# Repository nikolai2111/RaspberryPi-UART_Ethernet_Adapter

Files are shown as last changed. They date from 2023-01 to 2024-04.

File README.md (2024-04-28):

<!-- Improved compatibility of back to top link: See: https://github.com/othneildrew/Best-README-Template/pull/73 -->

<!--
*** Thanks for checking out the Best-README-Template. If you have a suggestion
*** that would make this better, please fork the repo and create a pull request
*** or simply open an issue with the tag "enhancement".
*** Don't forget to give the project a star!
*** Thanks again! Now go create something AMAZING! :D
-->

<!-- PROJECT SHIELDS -->
<!--
*** I'm using markdown "reference style" links for readability.
*** Reference links are enclosed in brackets [ ] instead of parentheses ( ).
*** See the bottom of this document for the declaration of the reference variables
*** for contributors-url, forks-url, etc. This is an optional, concise syntax you may use.
*** https://www.markdownguide.org/basic-syntax/#reference-style-links
-->
[][contributors-url]
[][forks-url]
[][stars-url]
[][issues-url]
[][license-url]

<!-- PROJECT LOGO -->
<br />
<div align="center">

<h3 align="center">Raspberry Pi UART to Ethernet Adapter</h3>

  <p align="center">
    This adapter board enables the creation of a stand-alone, network-compatible device using any Raspberry Pi compatible UART daughterboard.
    <br />
    <a href="https://github.com/nikolai2111/RaspberryPi-UART_Ethernet_Adapter"><strong>Explore the docs »</strong></a>
    <br />
    <br />
    <a href="https://github.com/nikolai2111/RaspberryPi-UART_Ethernet_Adapter">View Demo</a>
    ·
    <a href="https://github.com/nikolai2111/RaspberryPi-UART_Ethernet_Adapter/issues/new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">Report Bug</a>
    ·
    <a href="https://github.com/nikolai2111/RaspberryPi-UART_Ethernet_Adapter/issues/new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">Request Feature</a>
  </p>
</div>

<!-- TABLE OF CONTENTS -->
<details>
  <summary>Table of Contents</summary>
  <ol>
    <li>
      <a href="#about-the-project">About The Project</a>
      <ul>
        <li><a href="#built-with">Built With</a></li>
      </ul>
    </li>
    <li>
      <a href="#getting-started">Getting Started</a>
      <ul>
        <li><a href="#prerequisites">Prerequisites</a></li>
        <li><a href="#Configure WIZ750SR">Configure WIZ750SR</a></li>
        <li><a href="#Confgure Z-Wave JS UI">Confgure Z-Wave JS UI</a></li>
      </ul>
    </li>
    <li><a href="#usage">Usage</a></li>
    <li><a href="#roadmap">Roadmap</a></li>
    <li><a href="#contributing">Contributing</a></li>
    <li><a href="#license">License</a></li>
    <li><a href="#contact">Contact</a></li>
    <li><a href="#acknowledgments">Acknowledgments</a></li>
  </ol>
</details>

<!-- ABOUT THE PROJECT -->
## About The Project

This adapter board enables the creation of a stand-alone, network-compatible device using any Raspberry Pi compatible UART daughterboard. The adapter board is used to connect the daughterboard of the Raspberry Pi and [WIZ750SR](https://docs.wiznet.io/Product/S2E-Module/WIZ750SR)-TTL. The adapter board connects the daughterboard of the Raspberry Pi to the [WIZ750SR](https://docs.wiznet.io/Product/S2E-Module/WIZ750SR)-TTL. It also provides a 5V and 3.3V power supply where necessary.

The adapter board was initially designed to connect the [RaZberry 7 Pro](https://z-wave.me/products/razberry/#slide-1) to [Home Assistant](https://www.home-assistant.io/) via TCP, without using a Raspberry Pi as a server. It can also be used with any Raspberry Pi daughterboard that only needs the TTL-UART interface. However, the following README refers to the use of the [RaZberry 7 Pro](https://z-wave.me/products/razberry/#slide-1) with [Home Assistant](https://www.home-assistant.io/). It is possible to map three GPIOs to the header, although this has not been tested yet.

The board or as a kit (incl. [WIZ750SR](https://www.digikey.de/de/products/detail/wiznet/WIZ750SR-TTL/8789618)) can be purchased [here](https://www.tindie.com/products/nikolai2111/raspberry-pi-uart-to-ethernet-adapter/). The board is available with three power supply options (power supply not inlcuded):
* [Barrel Jack 2.1x5.5 mm](https://www.digikey.com/en/products/detail/cui-devices/PJ-037A/1644545)
* [USB Micro](https://www.digikey.de/de/products/detail/amphenol-cs-fci/10118194-0001LF/2785389)
* [USB C](https://www.digikey.ch/de/products/detail/gct/USB4125-GF-A/13547388)

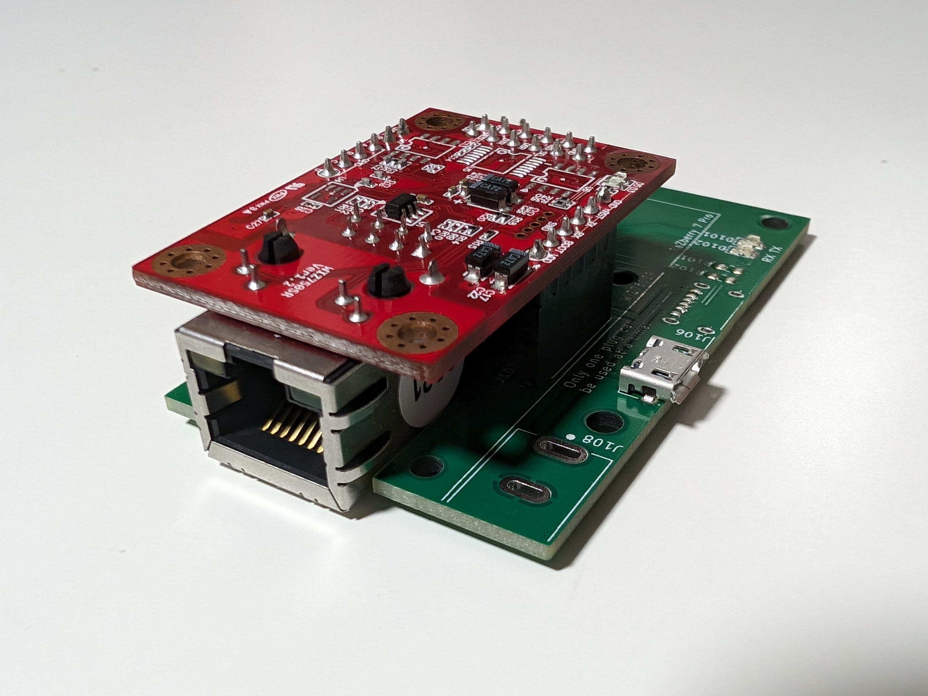
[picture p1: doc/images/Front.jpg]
Front


<p align="right">(<a href="#readme-top">back to top</a>)</p>

### Built With

* [][Kicad-url]

<p align="right">(<a href="#readme-top">back to top</a>)</p>

<!-- GETTING STARTED -->
## Getting Started

### Prerequisites
* [Home Assistant](https://www.home-assistant.io/) is running
* [Z-Wave JS UI](https://www.home-assistant.io/integrations/zwave_js/) installed
* [WIZnet-S2E-Tool-GUI](https://github.com/Wiznet/WIZnet-S2E-Tool-GUI) downloaded

### Configure WIZ750SR
1. Open the [WIZnet-S2E-Tool-GUI](https://github.com/Wiznet/WIZnet-S2E-Tool-GUI)
2. Click `Device Search`
3. Select device with double click
4. Set the `Basic Settings` as shown in the picture below
   
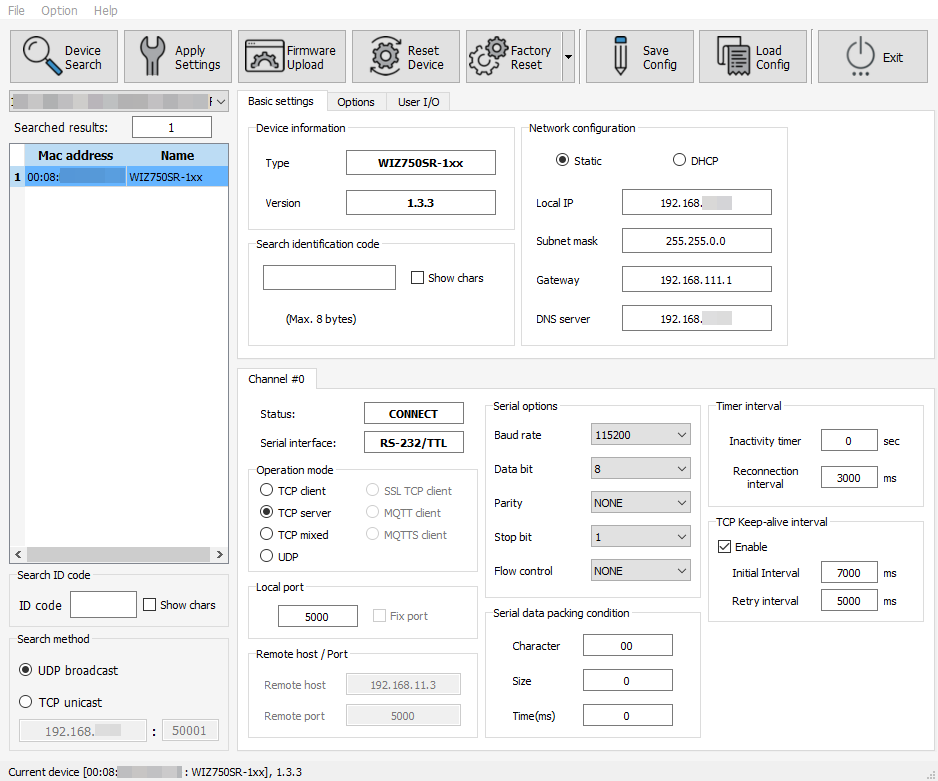
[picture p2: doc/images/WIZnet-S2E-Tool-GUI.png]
Basic Settings


### Confgure Z-Wave JS UI
1. Open [Home Assistant](homeassistant.local)
2. Open `Add-ons`
3. Click on `Z-Wave JS UI`
4. Start the add-on, if it's not running yet
5. Click on `OPEN WEB UI`
6. Go to `Settings`
7. Go to `Z-Wave`
8. And enter the IP and port below the `Serial Port` as shown in the picture blow. Use the scheme `tcp://your-ip:port`

Serial Port

<!-- USAGE EXAMPLES -->
## Usage

Use this space to show useful examples of how a project can be used. Additional screenshots, code examples and demos work well in this space. You may also link to more resources.

_For more examples, please refer to the [Documentation](https://example.com)_

<p align="right">(<a href="#readme-top">back to top</a>)</p>

<!-- ROADMAP -->
## Roadmap

* [ ] Test more than one device
* [ ] Offer [WIZ750SR](https://docs.wiznet.io/Product/S2E-Module/WIZ750SR) in the shop
* [ ] Offer PoE adapter in the shop

See the [open issues](https://github.com/nikolai2111/RaspberryPi-UART_Ethernet_Adapter/issues) for a full list of proposed features (and known issues).

<p align="right">(<a href="#readme-top">back to top</a>)</p>

<!-- CONTRIBUTING -->
## Contributing

Contributions are what make the open source community such an amazing place to learn, inspire, and create. Any contributions you make are **greatly appreciated**.

If you have a suggestion that would make this better, please fork the repo and create a pull request. You can also simply open an issue with the tag "enhancement".
Don't forget to give the project a star! Thanks again!

1. Fork the Project
2. Create your Feature Branch (`git checkout -b feature/AmazingFeature`)
3. Commit your Changes (`git commit -m 'Add some AmazingFeature'`)
4. Push to the Branch (`git push origin feature/AmazingFeature`)
5. Open a Pull Request

<p align="right">(<a href="#readme-top">back to top</a>)</p>

<!-- LICENSE -->
## License

Distributed under the [CERN-OHL-P](LICENSE) License. See `LICENSE` for more information. The license for all other sources remains the same and is still valid.

<p align="right">(<a href="#readme-top">back to top</a>)</p>

<!-- CONTACT -->
## Contact

Nikolai Zoller - [nikolai.zoller@hotmail.com](mailto:nikolai.zoller@hotmail.com)

Project Link: [https://github.com/nikolai2111/RaspberryPi-UART_Ethernet_Adapter](https://github.com/nikolai2111/RaspberryPi-UART_Ethernet_Adapter)

<p align="right">(<a href="#readme-top">back to top</a>)</p>

<!-- ACKNOWLEDGMENTS -->
## Acknowledgments

The main concept was initially proposed by an anonymous colleague. The development, production, and sale are carried out with their consent.

<p align="right">(<a href="#readme-top">back to top</a>)</p>

Source: [Best-README-Template](https://github.com/othneildrew/Best-README-Template)

<!-- MARKDOWN LINKS & IMAGES -->
<!-- https://www.markdownguide.org/basic-syntax/#reference-style-links -->
[contributors-shield]: https://img.shields.io/github/contributors/nikolai2111/RaspberryPi-UART_Ethernet_Adapter.svg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
[contributors-url]: https://github.com/nikolai2111/RaspberryPi-UART_Ethernet_Adapter/graphs/contributors
[forks-shield]: https://img.shields.io/github/forks/nikolai2111/RaspberryPi-UART_Ethernet_Adapter.svg?style=for-the-badge
[forks-url]: https://github.com/nikolai2111/RaspberryPi-UART_Ethernet_Adapter/network/members
[stars-shield]: https://img.shields.io/github/stars/nikolai2111/RaspberryPi-UART_Ethernet_Adapter.svg?style=for-the-badge
[stars-url]: https://github.com/nikolai2111/RaspberryPi-UART_Ethernet_Adapter/stargazers
[issues-shield]: https://img.shields.io/github/issues/nikolai2111/RaspberryPi-UART_Ethernet_Adapter.svg?style=for-the-badge
[issues-url]: https://github.com/nikolai2111/RaspberryPi-UART_Ethernet_Adapter/issues
[license-shield]: https://img.shields.io/github/license/nikolai2111/RaspberryPi-UART_Ethernet_Adapter.svg?style=for-the-badge
[license-url]: https://github.com/nikolai2111/RaspberryPi-UART_Ethernet_Adapter/blob/master/LICENSE.txt
[Kicad-logo]: https://upload.wikimedia.org/wikipedia/commons/5/59/KiCad-Logo.svg
[Kicad-url]: https://www.kicad.org/

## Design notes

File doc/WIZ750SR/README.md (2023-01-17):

# WIZ750SR

## Data sheet
### WIZ750SR Connector Specification
#### 6x2 Data Pin Connector
6x2 Data Pin Connector

#### 1x6 ISP Connector
1x6 ISP Connector

#### 1x6 Expansion GPIO & APP BOOT
1x6 Expansion GPIO & APP BOOT

### WIZ750SR Dimension
 -  45mm x 30mm (PCB board size)
 -  48mm x 30mm x 18mm (Included part size)

Rev1.2

## Links
 - [Overview WIZ750SR](https://www.wiznet.io/product-item/wiz750sr/)
 - [Data sheet WIZ750SR](https://docs.wiznet.io/Product/S2E-Module/WIZ750SR/datasheet)
 - [User's Manual-[EN]](https://docs.wiznet.io/Product/S2E-Module/WIZ750SR/users-manual-EN)
 - [Command Manual-[EN]](https://docs.wiznet.io/Product/S2E-Module/WIZ750SR/command-manual-EN)
 - [Trouble Shooting-[EN]](https://docs.wiznet.io/Product/S2E-Module/WIZ750SR/trouble-shooting-EN)
 - [WIZ750SR Series Downloads](https://docs.wiznet.io/Product/S2E-Module/WIZ750SR/download)
 - [Technical References](https://docs.wiznet.io/Product/S2E-Module/WIZ750SR/technical-references)

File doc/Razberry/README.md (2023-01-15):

# Razberry 2.1

## Data sheet

## Raspberry Pinout
Raspberry Pinout

## Links
 none

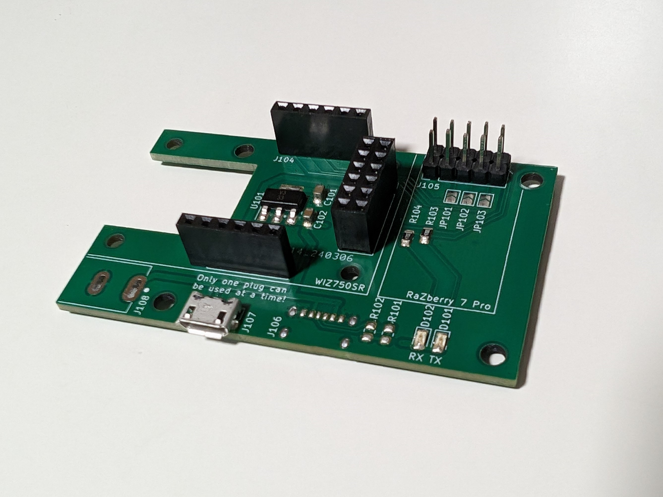
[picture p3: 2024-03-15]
doc/images/PCB-only.jpg

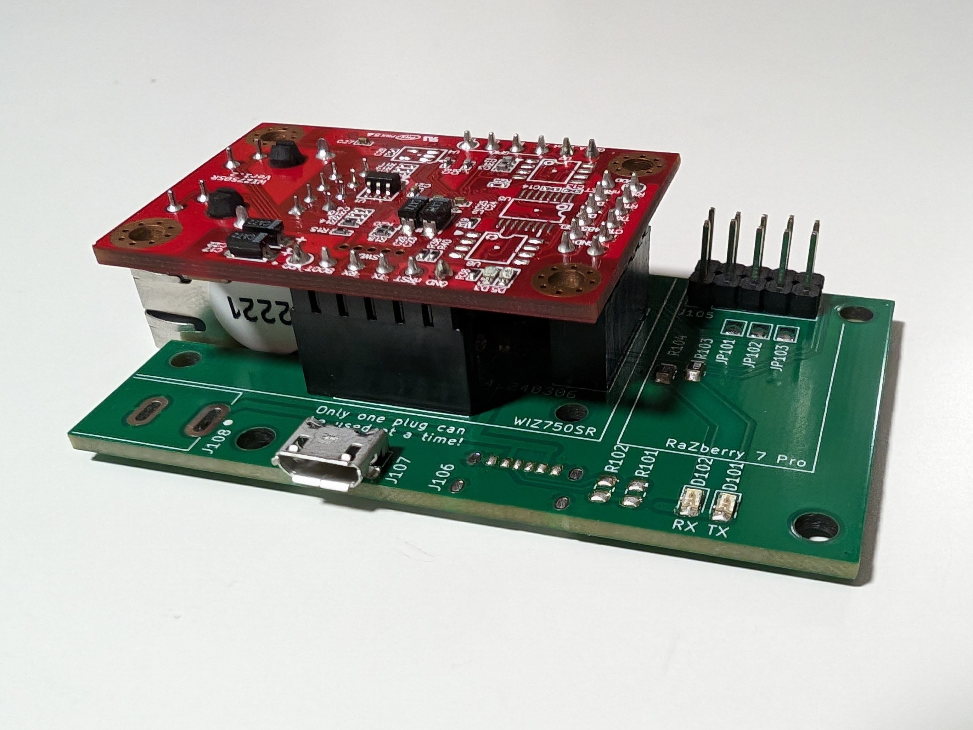
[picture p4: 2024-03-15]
doc/images/Side.jpg

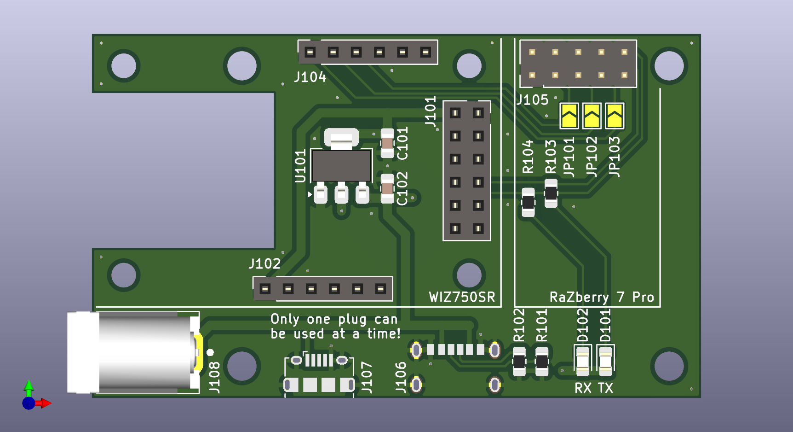
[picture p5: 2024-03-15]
PCB-3D_Top_B.png

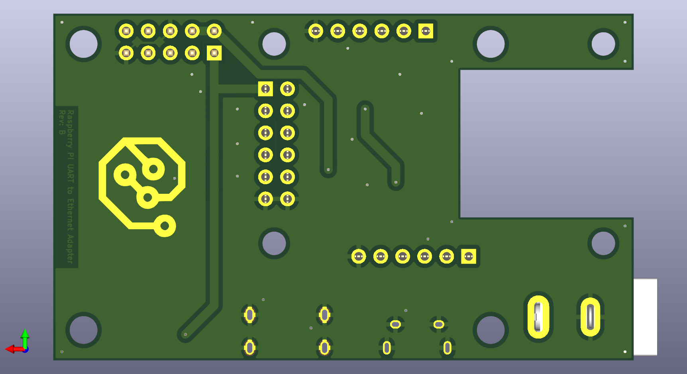
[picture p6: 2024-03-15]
PCB-3D_Bot_B.png

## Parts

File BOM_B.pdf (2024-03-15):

Reference | Value | Footprint | Qty | DNP | Manufacturer Part No. | Vendor | Vendor Part No.
C101 | 100µF | Capacitor_SMD:C_0805_2012Metric_Pad1.18x1.45mm_HandSolder | 1 | CL21A107MQYNNWE | Digikey | 1276-CL21A107MQYNNWECT-ND
C102 | 10µF | Capacitor_SMD:C_0805_2012Metric_Pad1.18x1.45mm_HandSolder | 1 | CL21A106KOQNNNE | Digikey | 1276-1096-1-ND
D101,D102 | GN | LED_SMD:LED_0805_2012Metric_Pad1.15x1.40mm_HandSolder | 2 | LTST-C171GKT | Digikey | 160-1423-1-ND
J101 | Conn_02x06_Odd_Even | Connector_PinSocket_2.54mm:PinSocket_2x06_P2.54mm_Vertical | 1 | RS2-12-G | Digikey | 2057-RS2-12-G-ND
J102,J104 | Conn_01x06 | Connector_PinSocket_2.54mm:PinSocket_1x06_P2.54mm_Vertical | 2 | RS1-06-G | Digikey | 2057-RS1-06-G-ND
J105 | Conn_02x05_Odd_Even | Connector_PinHeader_2.54mm:PinHeader_2x05_P2.54mm_Vertical | 1 | PH2-10-UA | Digikey | 2057-PH2-10-UA-ND
J106 | USB4125-GF-A | Connectors_User:GCT_USB4125-GF-A | 1 | USB4125-GF-A | Digikey | 2073-USB4125-GF-ACT-ND
J107 | USB_B_Micro | Connector_USB:USB_Micro-B_Amphenol_10118194_Horizontal | 1 | 10118194-0001LF | Digikey | 609-4618-1-ND
J108 | Barrel_Jack | Connector_User:CUI_PJ-037A_Board-Edge | 1 | PJ-037A | Digikey | CP-037A-ND
R101,R102 | 5.1k | Resistor_SMD:R_0805_2012Metric_Pad1.20x1.40mm_HandSolder | 2 | RC0805FR-075K1L | Digikey | 311-5.10KCRCT-ND
R103,R104 | 470R | Resistor_SMD:R_0805_2012Metric_Pad1.20x1.40mm_HandSolder | 2 | RC0805FR-07470RL | Digikey | 311-470CRCT-ND
U101 | TLV1117-33 | Package_TO_SOT_SMD:SOT-223-3_TabPin2 | 1 | TLV1117-33CDCYR | Digikey | 296-21112-1-ND

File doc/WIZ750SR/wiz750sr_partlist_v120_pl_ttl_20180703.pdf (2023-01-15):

Item | Q.ty | Reference | Part | Tech. Characteristics | Package
1 | 9 | C1,C6,C18,C19,C20,C21,C24,C25,C27 | 0.1uF | 50V-5% Ceramic | CASE 0402
2 | 4 | C17,C22,C23,C26 | 10uF/16V | Tantal CAP, A Size, 10uF/16V, +/-20% | EIA/IECQ 3216
3 | 2 | C2,C3 | 30pF | 25V-20% Ceramic | CASE 0402
4 | 2 | C8,C9 | 27pF | 50V-5% Ceramic | CASE 0402
5 | 1 | C7 | 1nF/2kV | 1nF/2kV Ceramic | CASE 1808(4520)
6 | 1 | D1 | Red LED | CHIP-LED, Red | CASE 0603
7 | 2 | D2,D3 | Blue LED | CHIP-LED, Blue | CASE 0603
8 | 2 | D4,D5 | Green LED | CHIP-LED, Green | CASE 0603
9 | 1 | J1 | 2.54mm Pin haeder 6x2 | 2.54mm Pin haeder 6x2, Male | DIP
10 | 2 | J2,J4 | 2.54mm Pin haeder 1x6 | 2.54mm Pin haeder 1x6, Male | DIP
11 | 2 | L1,L2 | HH-1M1608-121JT | Bead for Power Line, 120[ohm] | CASE 0603
12 | 1 | P1 | BS-RB10005 | Transformer + RJ45 + LED, Industrial, UDE | DIP
13 | 3 | R18,R19,R20 | 5.1K | 1/10W-5% SMD | CASE 0402
14 | 1 | R16 | 6.19K 1% | 1/10W-1% SMD | CASE 0402
15 | 1 | R1 | 1M | 1/10W-5% SMD | CASE 0402
16 | 5 | R14,R15,R36,R39,R40 | 330R | 1/10W-5% SMD | CASE 0402
17 | 2 | R37,R38 | 1K | 1/10W-5% SMD | CASE 0402
18 | 6 | R2,R6,R13,R17,R33,R42 | 4.7K | 1/10W-5% SMD | CASE 0402
19 | 4 | R21,R22,R23,R24 | 0R | 1/10W-5% SMD | CASE 0402
20 | 4 | R4,R5,R7,R8 | 3.3R | 1/10W-5% SMD | CASE 0402
21 | 1 | U1 | TPD4S009DBVR | 4-Channel ESD Protection IC | SOT-23(DBV)
22 | 1 | U2 | W7500P | WIZnet ARM Cortex-M0, Add PHY | LQFP64
23 | 1 | U3 | MIC811SUY | Microprocessor Reset Circuits | SOT-143
24 | 1 | Y1 | 12MHz (TZ1067B-12MHz)X-tal 12MHz,3.2x2.5 SMD, CL=20pF | | SMD3225, 4-PAD
25 | 1 | Y2 | 82J0626-25.000MHz | X-tal 25MHz,3.2x2.5 SMD, CL=18pF,Industrial,ITTI | SMD3225, 4-PAD
26 | 1 | J3 | 1.27mm Pin haeder 1x5 | Not Mount | DIP
27 | 4 | R9,R10,R11,R12 | 49R9 1% | 1/10W-1% SMD (Not Mount) | CASE 0402
28 | 4 | R26,R27,R28,R29 | 200R | Not Mount
29 | 2 | R30,R31 | 120R | Not Mount
30 | 1 | U4 | 24AA16T-I/OT | EEPROM 2Kbyte (Not Mount) | SOT-23
31 | 1 | U5 | SP3232EBEY | Not Mount
32 | 2 | U6,U7 | SP3485EN-L | Not Mount
33 | 10 | C4,C5,C10,C11,C12,C13,C14,C15,C16,C28 | 0.1uF | Not Mount
34 | 5 | R3,R25,R34,R35,R41 | 4.7K | Not Mount
35 | 1 | | PCB | 4-Layer 45mm x 30mm

# WIZ750SR V1.2.0_TTL_Version Partlist

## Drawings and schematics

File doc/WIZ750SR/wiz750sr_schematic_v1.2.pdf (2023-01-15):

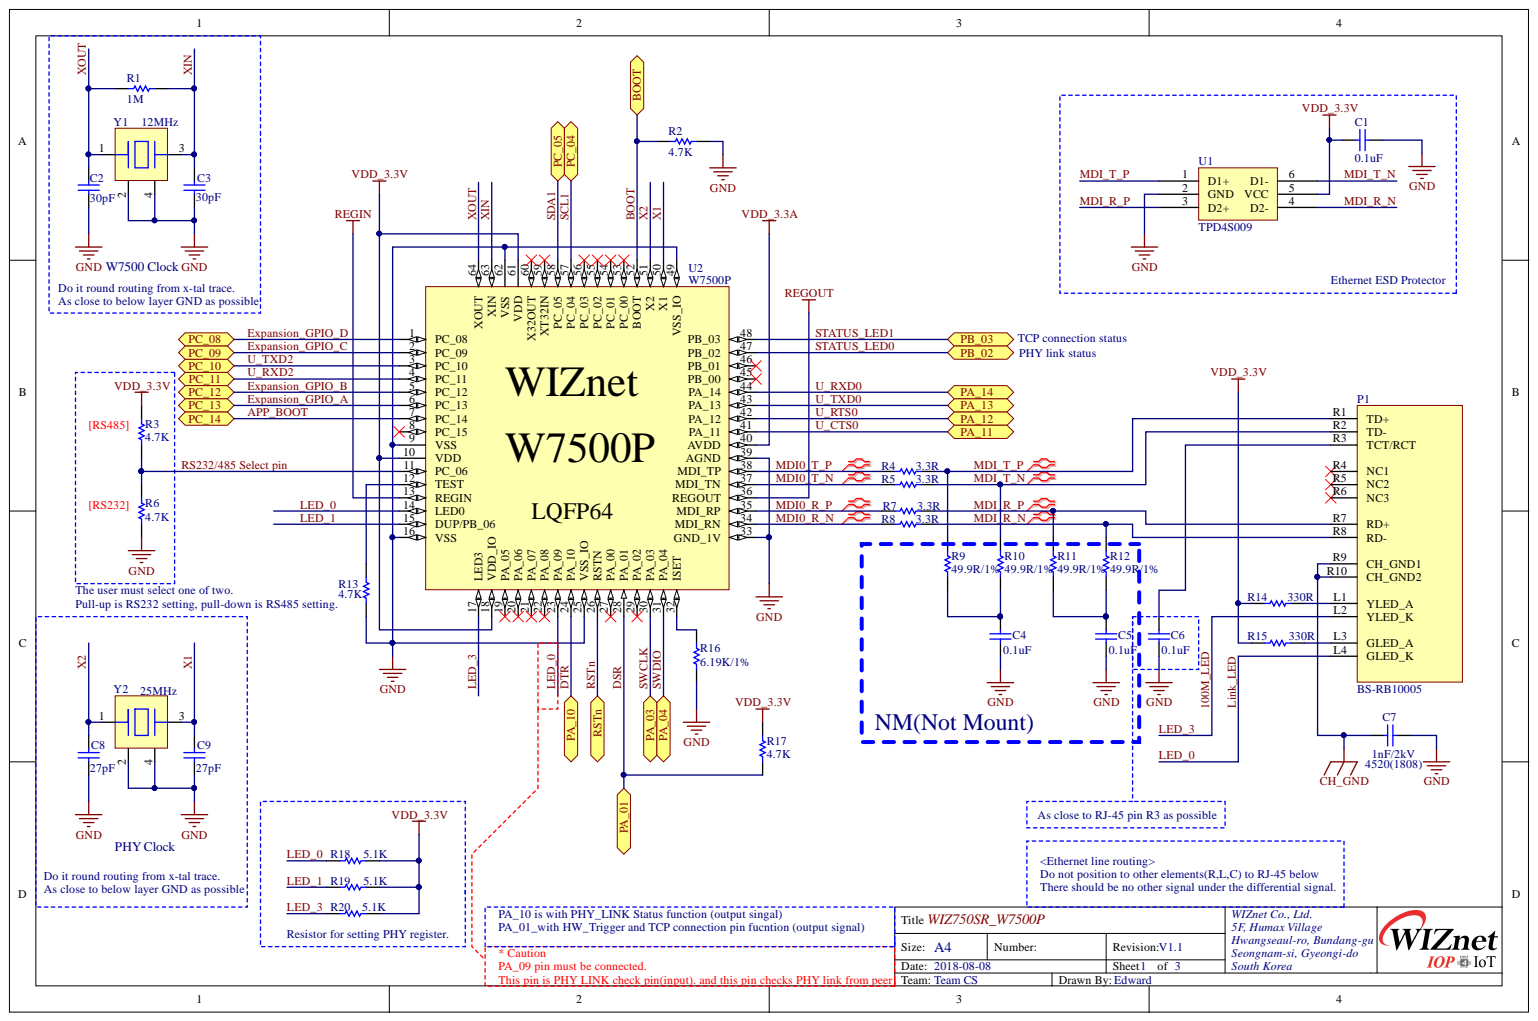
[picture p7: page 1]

48 SS_IO 49 X1 50 X2 51 BOOT 52 PC_00 53 PC_01 54 PC_02 55 PC_03 56 PC_04 57 PC_05 58 XT32IN 59 X32OUT 60 VDD 61 VSS 62 XIN 63 XOUT 64

Do it round routing from x-tal trace.
As close to below layer GND as possible

ISET 32 GND_1V 33 MDI_RN 34 MDI_RP 35 REGOUT 36 MDI_TN 37 MDI_TP 38 AGND 39 AVDD 40 PA_11 41 PA_12 42 PA_13 43 PA_14 44 PB_00 45 PB_01 46 PB_02 47 PB_03 V

U_TXD0
U_RTS0
U_CTS0 | TD- R2

VSS 9 | | | | TCT/RCT R3

REGIN 13

CH_GND1 R9
CH_GND2 R10

The user must select one of two.
Pull-up is RS232 setting, pull-down is RS485 setting.

YLED_K L2 YLED_A L1

As close to RJ-45 pin R3 as possible

<Ethernet line routing>
Do not position to other elements(R,L,C) to RJ-45 below
There should be no other signal under the differential signal.

PA_10 is with PHY_LINK Status function (output singal) PA_01_with HW_Trigger and TCP connection pin fucntion (output signal) | WIZ750SR_W7500P Title | WIZnet Co., Ltd. 5F, Humax Village Hwangseaul-ro, Bundang-gu Seongnam-si, Gyeongi-do South Korea

Resistor for setting PHY register.

* Caution
PA_09 pin must be connected.
This pin is PHY LINK check pin(input). and this pin checks PHY link from peer

A4 Size: | Number: | Revision: V1.1
Date: 2018-08-08 | | Sheet of 3
Team: Team CS | Drawn By: Edward

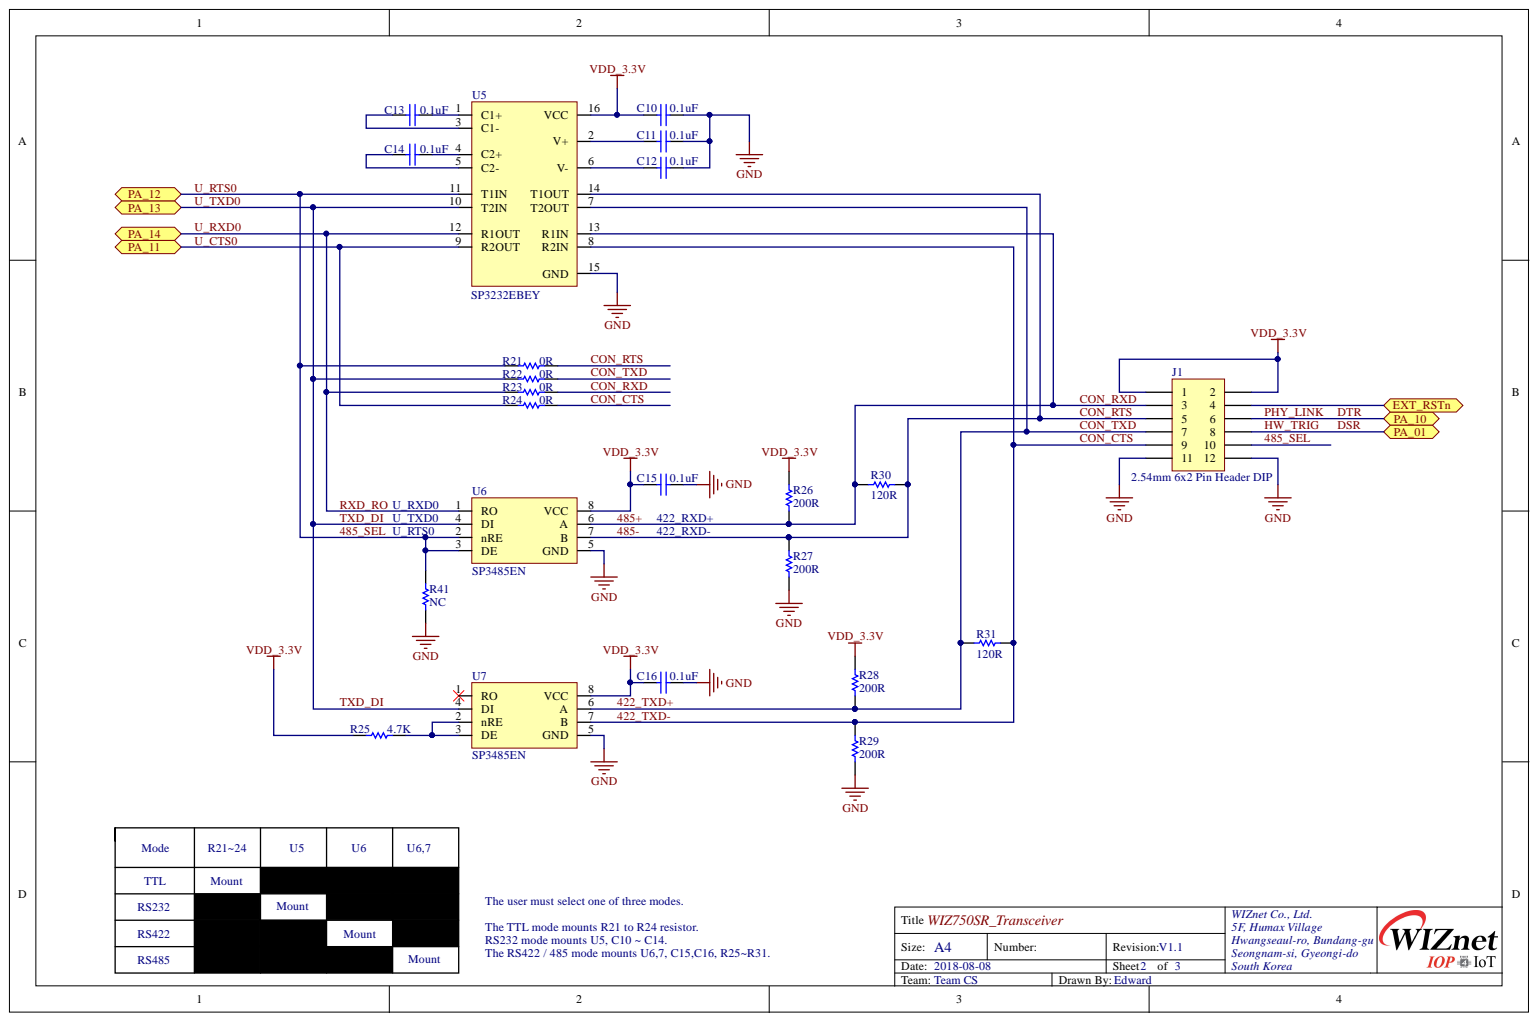
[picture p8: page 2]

CO N _ T X D
CO N _CT S

4 8 5 _SE L U _ RTS0 | 2 | | 7 4 8 5 -4 2 2 _RX D -

4 | | 6 4 2
2 | | 7 4 2 2 _ T X D -

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

A4 Team CS Size: | N umber: | Rev i s i o n : V 1.1

8-0 | | Sheet o f

Draw n By : E d ward

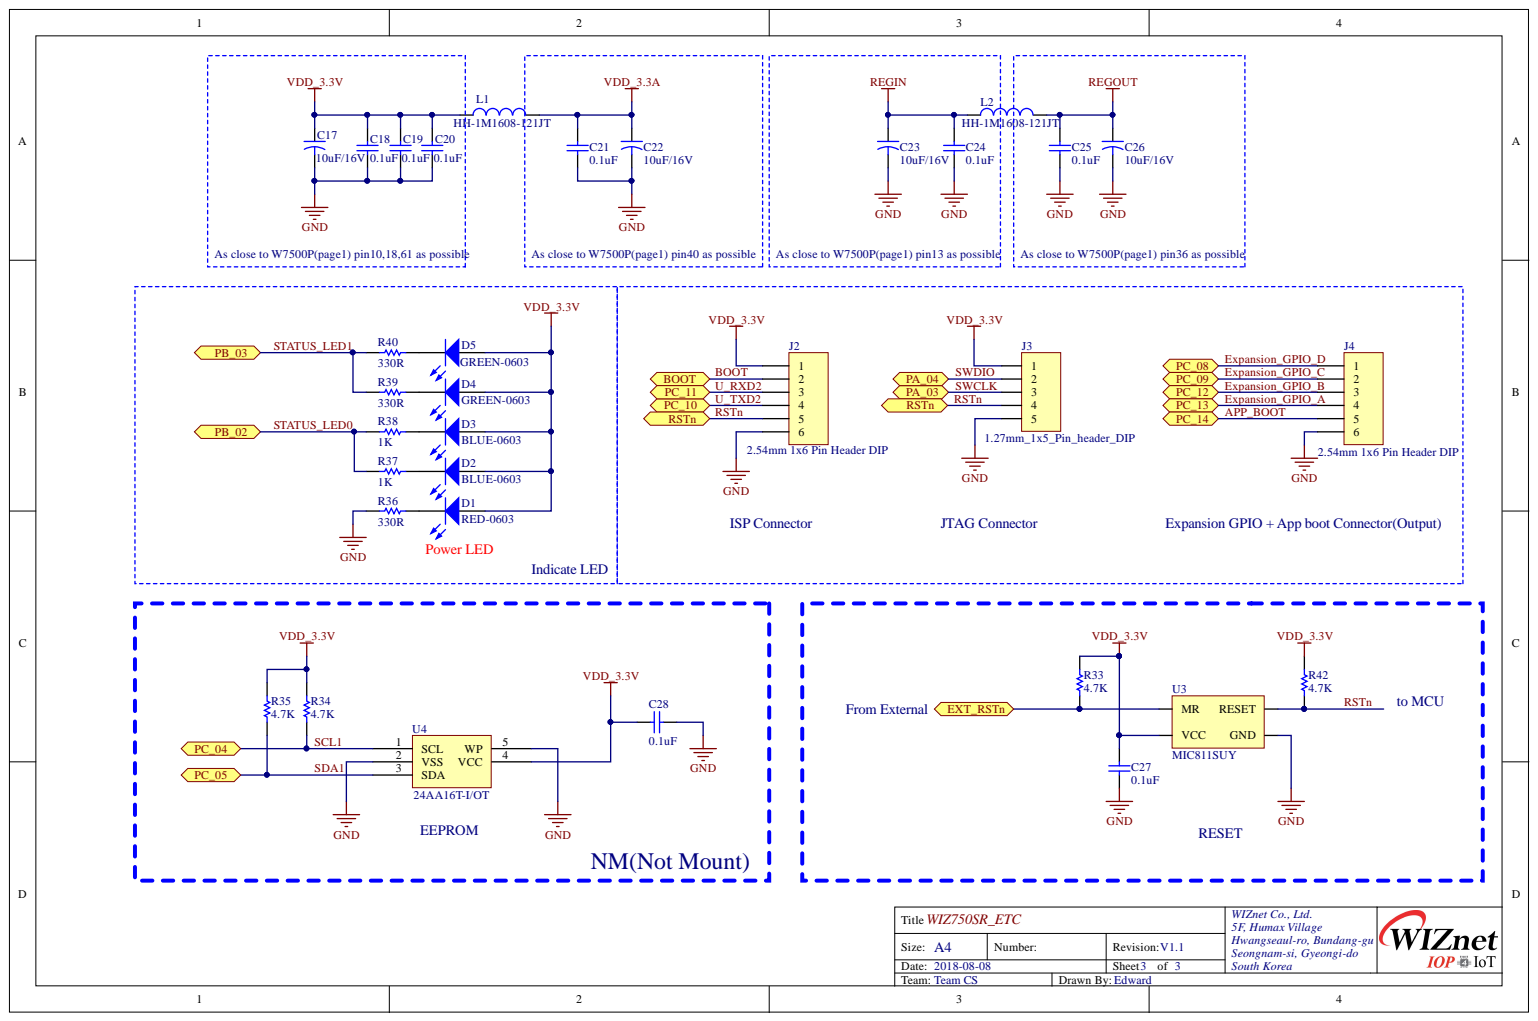
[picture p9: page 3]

to MCU From External

WIZ750SR_ETC Title | WIZnet Co., Ltd. 5F, Humax Village Hwangseaul-ro, Bundang-gu Seongnam-si, Gyeongi-do South Korea

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

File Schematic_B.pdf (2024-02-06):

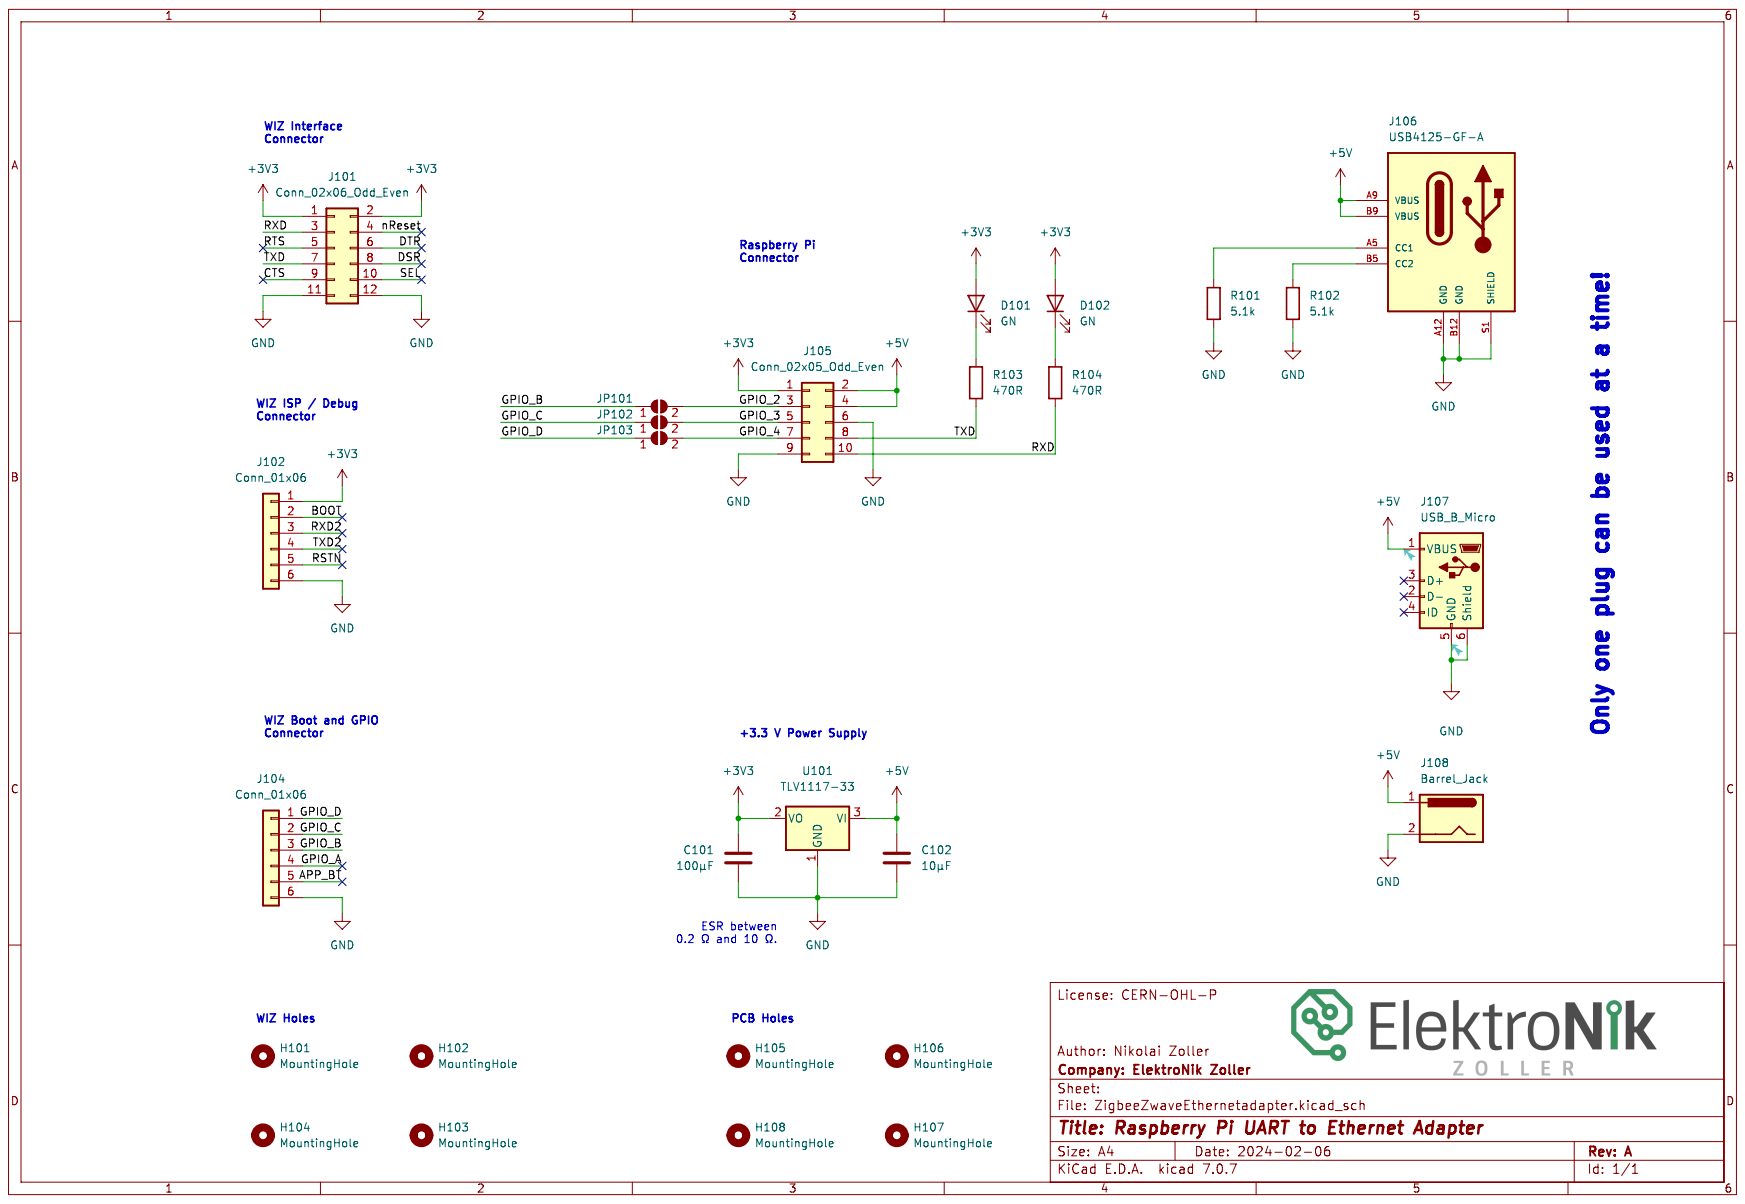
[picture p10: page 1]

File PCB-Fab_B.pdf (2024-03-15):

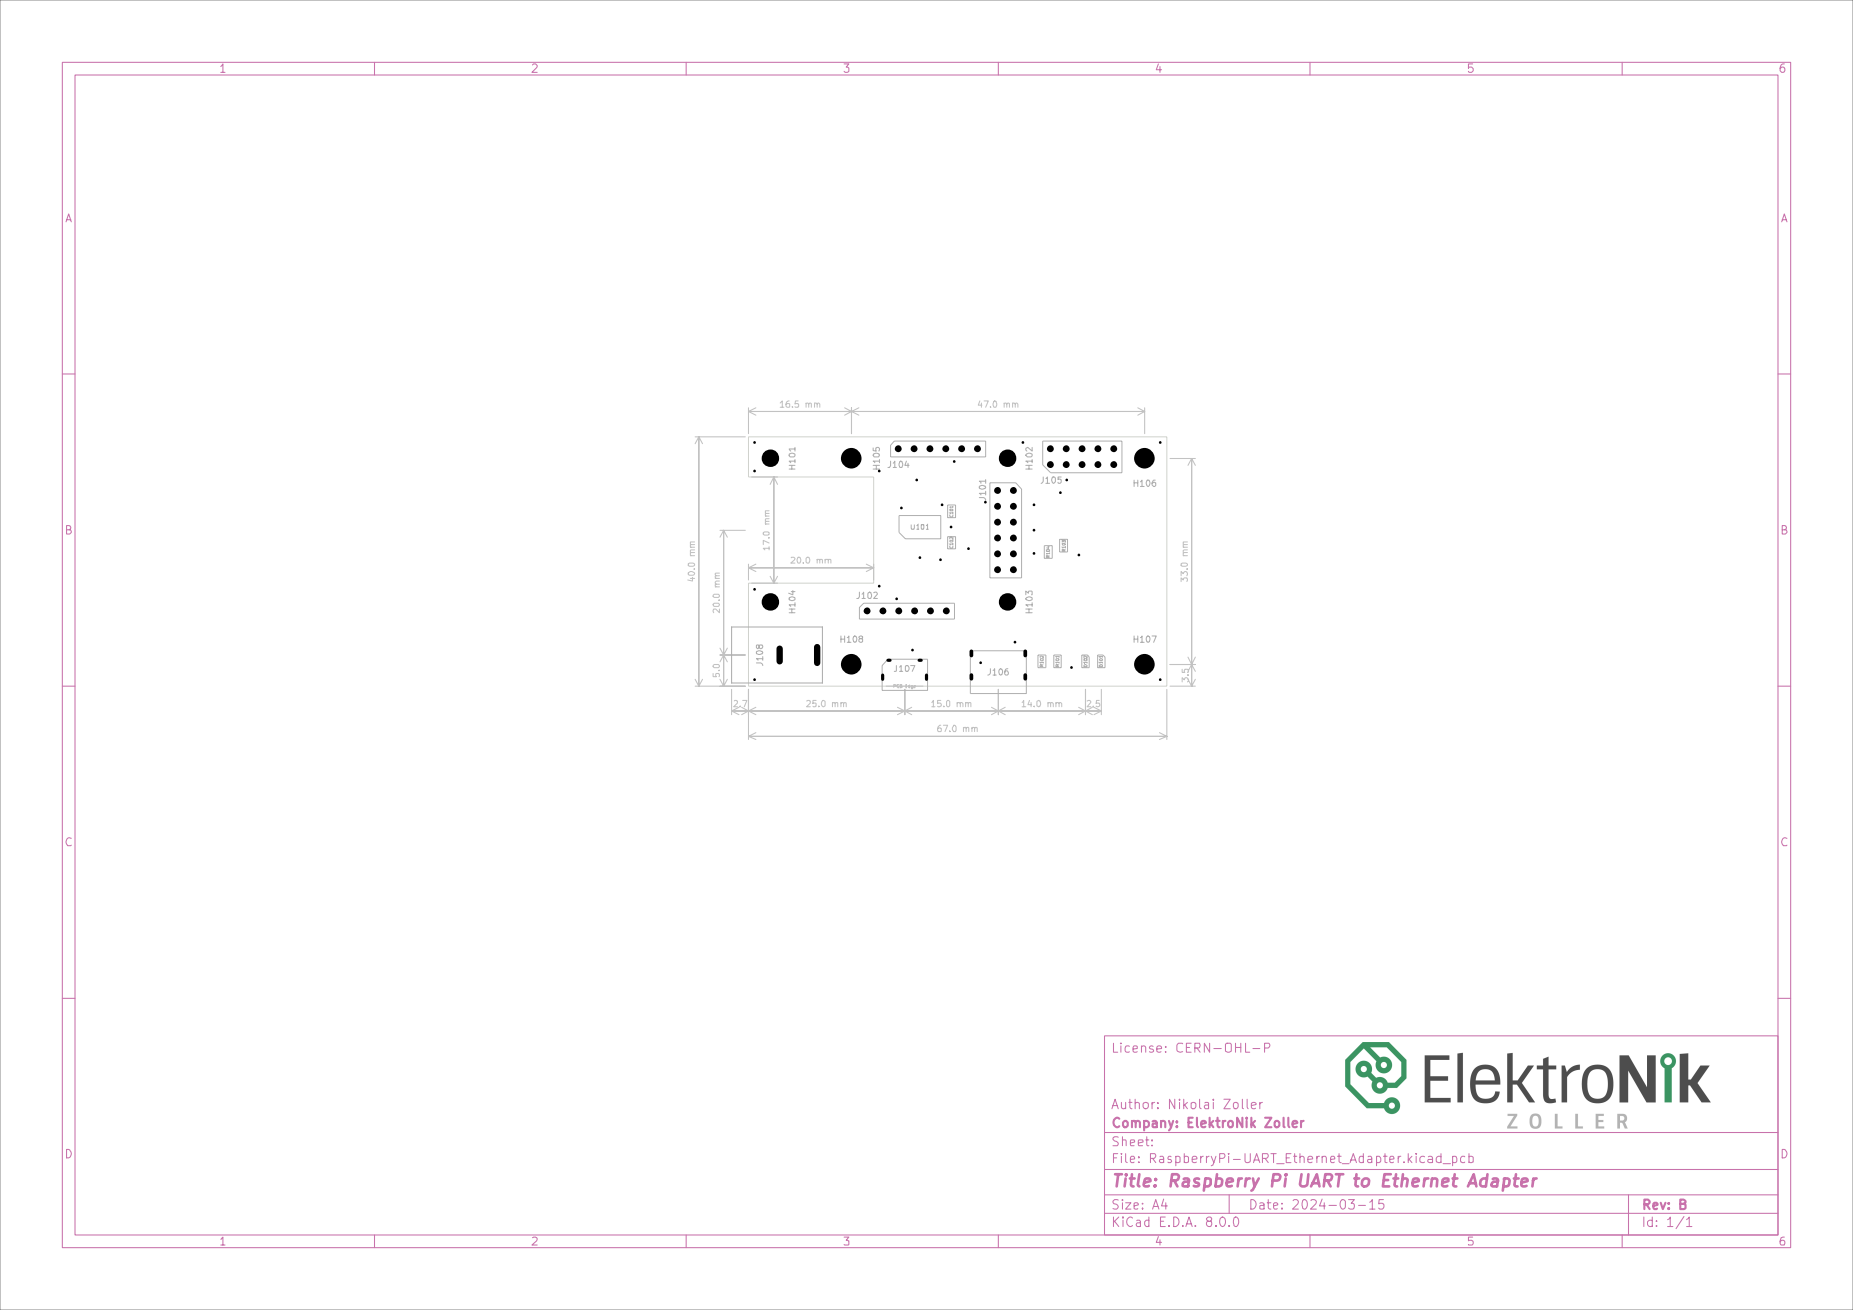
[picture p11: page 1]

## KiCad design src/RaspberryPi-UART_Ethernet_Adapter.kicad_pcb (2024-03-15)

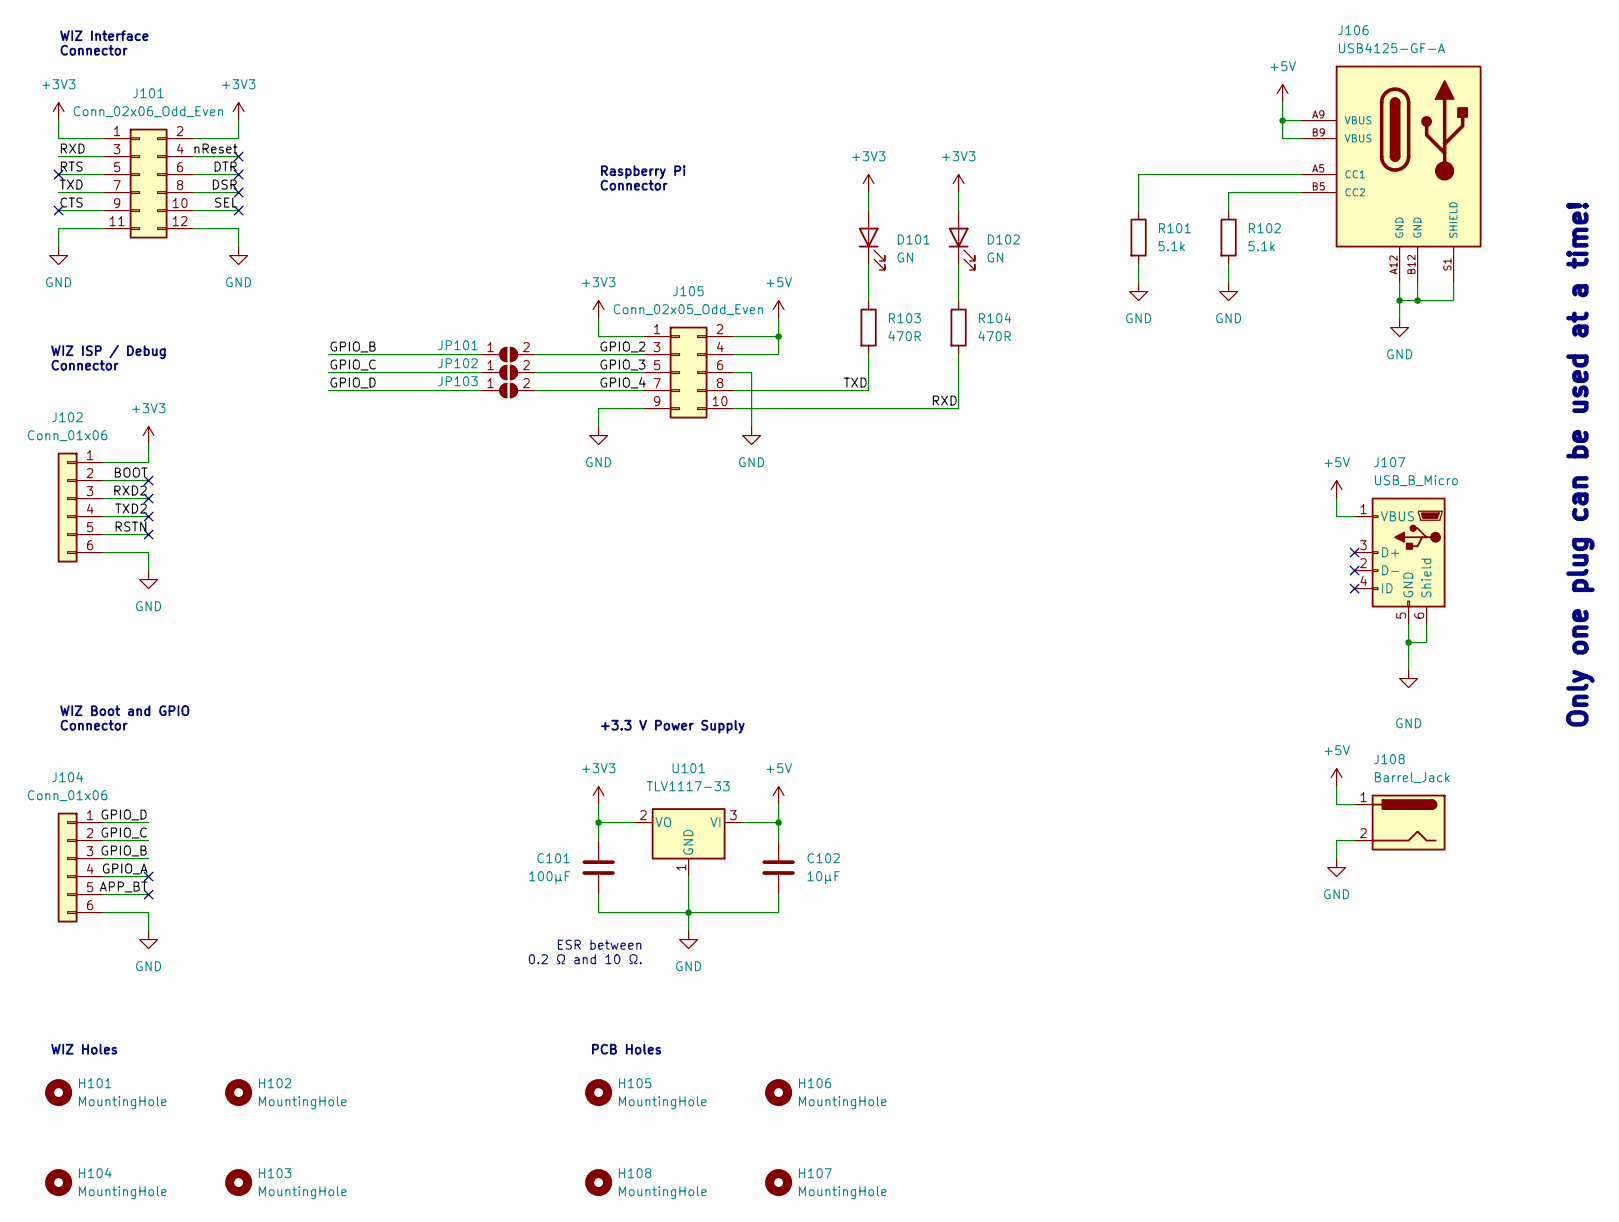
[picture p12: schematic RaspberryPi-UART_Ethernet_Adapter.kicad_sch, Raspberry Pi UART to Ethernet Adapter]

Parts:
C101: 100µF; C_0805_2012Metric_Pad1.18x1.45mm_HandSolder; Manufacturer Part No. CL21A107MQYNNWE
C102: 10µF; C_0805_2012Metric_Pad1.18x1.45mm_HandSolder; Manufacturer Part No. CL21A106KOQNNNE
D101, D102: GN; LED_0805_2012Metric_Pad1.15x1.40mm_HandSolder; Manufacturer Part No. LTST-C171GKT
H101, H102, H103, H104: MountingHole; MountingHole_2.7mm_M2.5_DIN965
H105, H106, H107, H108: MountingHole; MountingHole_3.2mm_M3_DIN965
J101: Conn_02x06_Odd_Even; PinSocket_2x06_P2.54mm_Vertical; Manufacturer Part No. RS2-12-G
J102, J104: Conn_01x06; PinSocket_1x06_P2.54mm_Vertical; Manufacturer Part No. RS1-06-G
J105: Conn_02x05_Odd_Even; PinHeader_2x05_P2.54mm_Vertical; Manufacturer Part No. PH2-10-UA
J106: USB4125-GF-A; GCT_USB4125-GF-A; Manufacturer Part No. USB4125-GF-A
J107: USB_B_Micro; USB_Micro-B_Amphenol_10118194_Horizontal; Manufacturer Part No. 10118194-0001LF
J108: Barrel_Jack; CUI_PJ-037A_Board-Edge; Manufacturer Part No. PJ-037A
JP101, JP102, JP103: SolderJumper_2_Open; SolderJumper-2_P1.3mm_Open_TrianglePad1.0x1.5mm
R101, R102: 5.1k; R_0805_2012Metric_Pad1.20x1.40mm_HandSolder; Manufacturer Part No. RC0805FR-075K1L
R103, R104: 470R; R_0805_2012Metric_Pad1.20x1.40mm_HandSolder; Manufacturer Part No. RC0805FR-07470RL
U101: TLV1117-33; SOT-223-3_TabPin2; Manufacturer Part No. TLV1117-33CDCYR

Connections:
+3V3: C101.1, D101.2 (A), D102.2 (A), J101.1, J101.2, J102.1, J105.1, U101.2 (VO)
+5V: C102.1, J105.2, J105.4, J106.A9 (VBUS), J106.B9 (VBUS), J107.1 (VBUS), J108.1, U101.3 (VI)
/APP_BT: J104.5
/BOOT: J102.2
/CTS: J101.9
/DSR: J101.8
/DTR: J101.6
/GPIO_2: J105.3, JP101.2 (B)
/GPIO_3: J105.5, JP102.2 (B)
/GPIO_4: J105.7, JP103.2 (B)
/GPIO_A: J104.4
/GPIO_B: J104.3, JP101.1 (A)
/GPIO_C: J104.2, JP102.1 (A)
/GPIO_D: J104.1, JP103.1 (A)
/RSTN: J102.5
/RTS: J101.5
/RXD: J101.3, J105.10, R104.2
/RXD2: J102.3
/SEL: J101.10
/TXD: J101.7, J105.8, R103.2
/TXD2: J102.4
/nReset: J101.4
GND: C101.2, C102.2, J101.11, J101.12, J102.6, J104.6, J105.6, J105.9, J106.A12 (GND), J106.B12 (GND), J106.S1 (SHIELD), J107.5 (GND), J107.6 (Shield), J108.2, R101.2, R102.2, U101.1 (GND)
unnamed: D101.1 (K), R103.1
unnamed: D102.1 (K), R104.1
unnamed: J106.A5 (CC1), R101.1
unnamed: J106.B5 (CC2), R102.1

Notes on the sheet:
+3.3 V Power Supply
WIZ Boot and GPIO Connector
ESR between 0.2 Ω and 10 Ω.
Only one plug can be used at a time!
WIZ ISP / Debug Connector
Raspberry Pi Connector
WIZ Holes
PCB Holes
WIZ Interface Connector

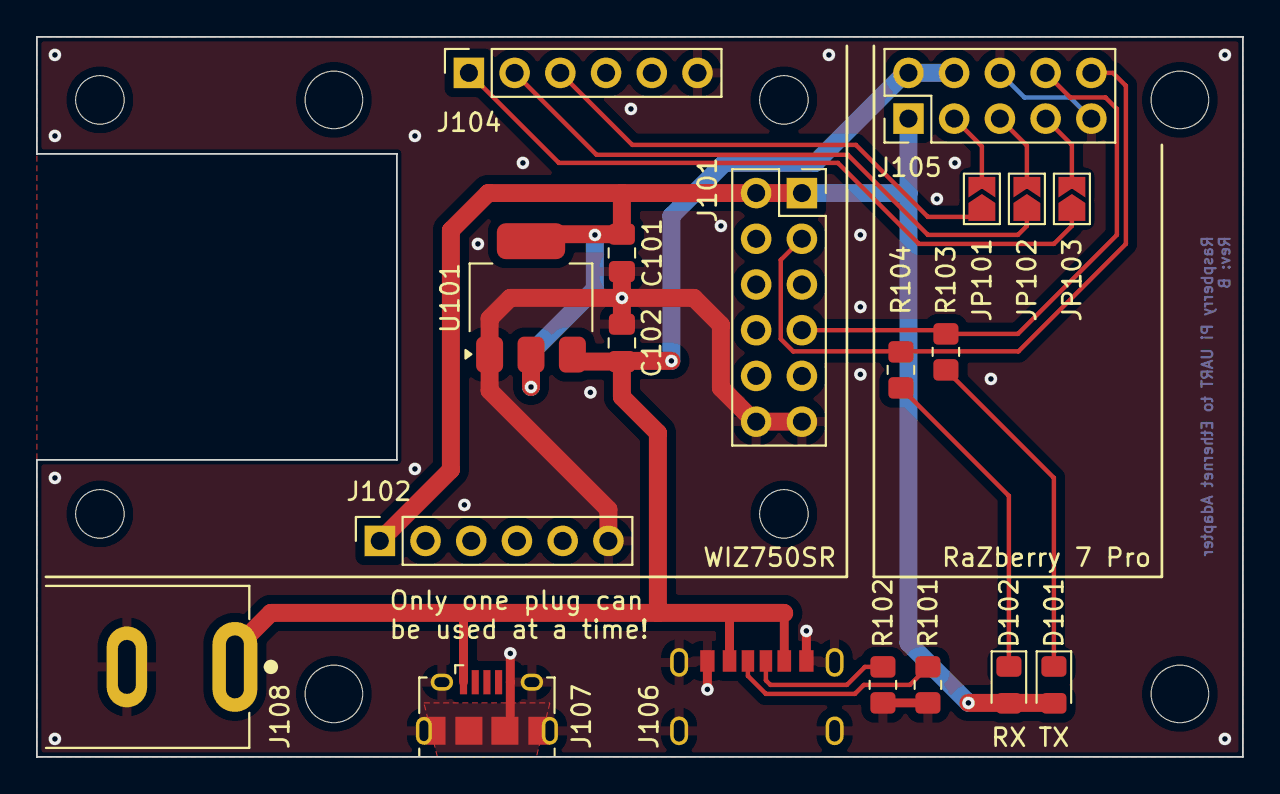
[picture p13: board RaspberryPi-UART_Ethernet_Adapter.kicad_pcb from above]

Board: 2 copper layers, 67.0 x 40.0 mm, 27 parts (0 on the bottom side), 15 nets.

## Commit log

2022-12-31 Add: KiCad Project
    [ZigbeeZwaveEthernetadapter.kicad_pcb, ZigbeeZwaveEthernetadapter.kicad_sch]
2023-01-15 Add: Infos and data for the WIZ750SR
    [wiz750sr_partlist_v120_pl_ttl_20180703.xls]
2023-01-15 Add: Basic schematic with voltage regulator, WIZ750SR, RasPi and power connectors
    [ZigbeeZwaveEthernetadapter.kicad_sch]
2023-01-15 Mod: Finished schematic, changed linear regulator and added second pinout
    [ZigbeeZwaveEthernetadapter.kicad_sch]
2023-01-15 Add: Schematic as a pdf
2023-01-16 Mod: LDO (U1) from LM2940 to LM3940
    [ZigbeeZwaveEthernetadapter.kicad_sch]
2023-01-16 Add: Data for USB Type-C connector such as data sheets, drawings and 3D model
    [USB4125-GF-A_REVA2.step]
2023-01-16 Add: USB4125-GF-A to the project symbol and footprint library
2023-01-16 Add: A file which got forgotten from the footprint library
2023-01-16 Mod: Symbol from USB Type-C receptacle and assigned footprint
    [ZigbeeZwaveEthernetadapter.kicad_sch]
2023-01-16 Add: 3D model to the footprint library
    [USB4125-GF-A.step]
2023-01-16 Mod: Exported new schematics
2023-01-16 Mod: Assigned the footprints of the pin header and sockets
    [ZigbeeZwaveEthernetadapter.kicad_sch]
2023-01-16 Mod: Assigned more footprints to the capacitors and resistors
    [ZigbeeZwaveEthernetadapter.kicad_sch]
2023-01-16 Add: Data for DC-Jack with 3D model
    [PJ-037A.step]
2023-01-16 Mod: Moved models to the corresponding libraries
    [PJ-037A.step]
2023-01-16 Mod: Assigned footprint for LDO, Micro USB and Barrel-Jack
    [ZigbeeZwaveEthernetadapter.kicad_sch]
2023-01-16 Add: Exported schematic
2023-01-17 Mod: Changed footprint of U1
    [ZigbeeZwaveEthernetadapter.kicad_sch]
2023-01-17 Add: Solder bridges and RX and TX LEDs
    [ZigbeeZwaveEthernetadapter.kicad_sch]
2023-02-01 Mod: Footprint of the GCT_USB4125-GF-A, moved it to the global library.
    [ZigbeeZwaveEthernetadapter.kicad_sch]
2023-02-02 Add: PCB Layout to the project, almost finished
    [ZigbeeZwaveEthernetadapter.kicad_pcb, ZigbeeZwaveEthernetadapter.kicad_sch]
2023-03-06 Mod: Schematic, moved footprint to global library own
    [ZigbeeZwaveEthernetadapter.kicad_sch]
2023-04-25 Mod: Migrated to KiCAD 7.0
    [ZigbeeZwaveEthernetadapter.kicad_pcb, ZigbeeZwaveEthernetadapter.kicad_sch]
2024-01-26 Mod: Updated project and adapted template.
    [ZigbeeZwaveEthernetadapter.kicad_pcb, ZigbeeZwaveEthernetadapter.kicad_sch, wiz750sr_partlist_v120_pl_ttl_20180703.xls]
2024-01-26 Add: BOM_A.pdf
    [BOM_A.xlsx, ZigbeeZwaveEthernetadapter.kicad_sch]
2024-01-26 Mod: Schematic and PCB-Layout, finished new Version.
    [ZigbeeZwaveEthernetadapter.kicad_pcb, ZigbeeZwaveEthernetadapter.kicad_sch]
2024-01-26 Add: Gerber files
2024-01-27 Mod: ZigbeeZwaveEthernetadapter.kicad_pcb, removed DRC errors and warnings.
    [ZigbeeZwaveEthernetadapter.kicad_pcb]
2024-02-06 Mod: LEDs for RXD and TXD, changed from Pull-Down to Pull-Up resistors and changed their value. Re-exported all the files.
    [BOM_A.xlsx, ZigbeeZwaveEthernetadapter.kicad_pcb, ZigbeeZwaveEthernetadapter.kicad_sch]
2024-02-06 Mod: Re-exported gerbers and renamed the .zip
2024-02-06 Mod: Renamed gerbers
2024-03-03 Mod: Updated project to KiCad 8.0
    [ZigbeeZwaveEthernetadapter.kicad_pcb, ZigbeeZwaveEthernetadapter.kicad_sch]
2024-03-03 Mod: ZigbeeZwaveEthernetadapter.kicad_sch, changes part no. of C101
    [BOM_A.xlsx, ZigbeeZwaveEthernetadapter.kicad_sch]
2024-03-15 Mod: Renamed project form ZigbeeZwaveEthernetadapter to RaspberryPi-UART_Ethernet_Adapter
    [RaspberryPi-UART_Ethernet_Adapter.kicad_pcb, RaspberryPi-UART_Ethernet_Adapter.kicad_sch]
2024-03-15 Mod: Manufacturer no. & Vendor no. of J105. Changed from socket header to pin header. Close #3
    [BOM_A.xlsx, BOM_B.xlsx, RaspberryPi-UART_Ethernet_Adapter.kicad_sch]
2024-03-15 Mod: Footprint J106, added front paste layer, closes #1. Moved logo G1 in the middle of the plane, closes #4.
    [RaspberryPi-UART_Ethernet_Adapter.kicad_pcb, RaspberryPi-UART_Ethernet_Adapter.kicad_sch]

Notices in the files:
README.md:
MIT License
